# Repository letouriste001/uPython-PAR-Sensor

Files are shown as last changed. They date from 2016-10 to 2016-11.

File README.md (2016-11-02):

# uPython-PAR-Sensor

## Introduction
Cette librairie est écrite pour un capteur TSL 230 RD qui nous permet de mesurer le PAR
L’ensoleillement représente la mesure d’irradiance du PAR  (Photosynthetically active radiation). Le PAR est le rayonnement nécessaire à la photosynthèse qui se situe sur une plage de 400 à 700 nm de longueur d’onde , c’est à dire une grande partie du spectre du domaine visible (fig.1).

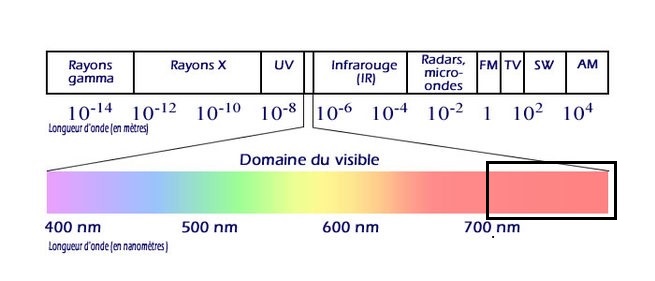
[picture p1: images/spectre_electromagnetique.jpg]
Spectre électromagnétique


Figure 1 Spectre électromagnétique, agrandissement sur le spectre visible. En noir, la partie du spectre visible non utilisée dans le PAR.

Pour mesurer la fiabilité du capteur TSL 230 RD on l’a comparé au capteur SUD033 couplet a un IL1700. Après une journée de mesure on obtient les courbes suivantes (fig.2)

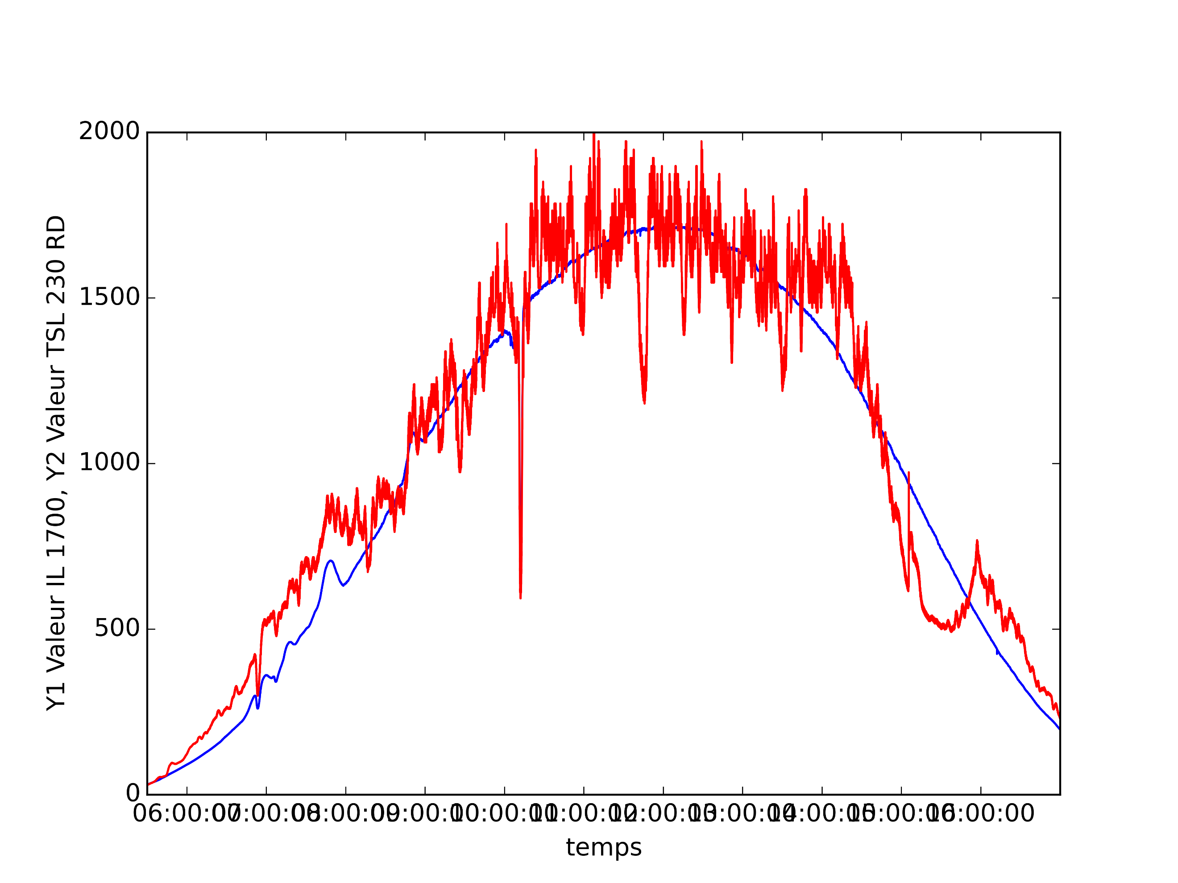
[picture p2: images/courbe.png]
Courbe des capteurs


Figure 2 Graphique de mesure des capteurs IL1700 et TSL 230 RD

La courbe rouge a été mise à l’échelle d’un facteur trois pour mieux visualiser le fait que les deux courbes sont similaires.
On applique la régression linaire sur les valeurs des capteurs (fig.3).

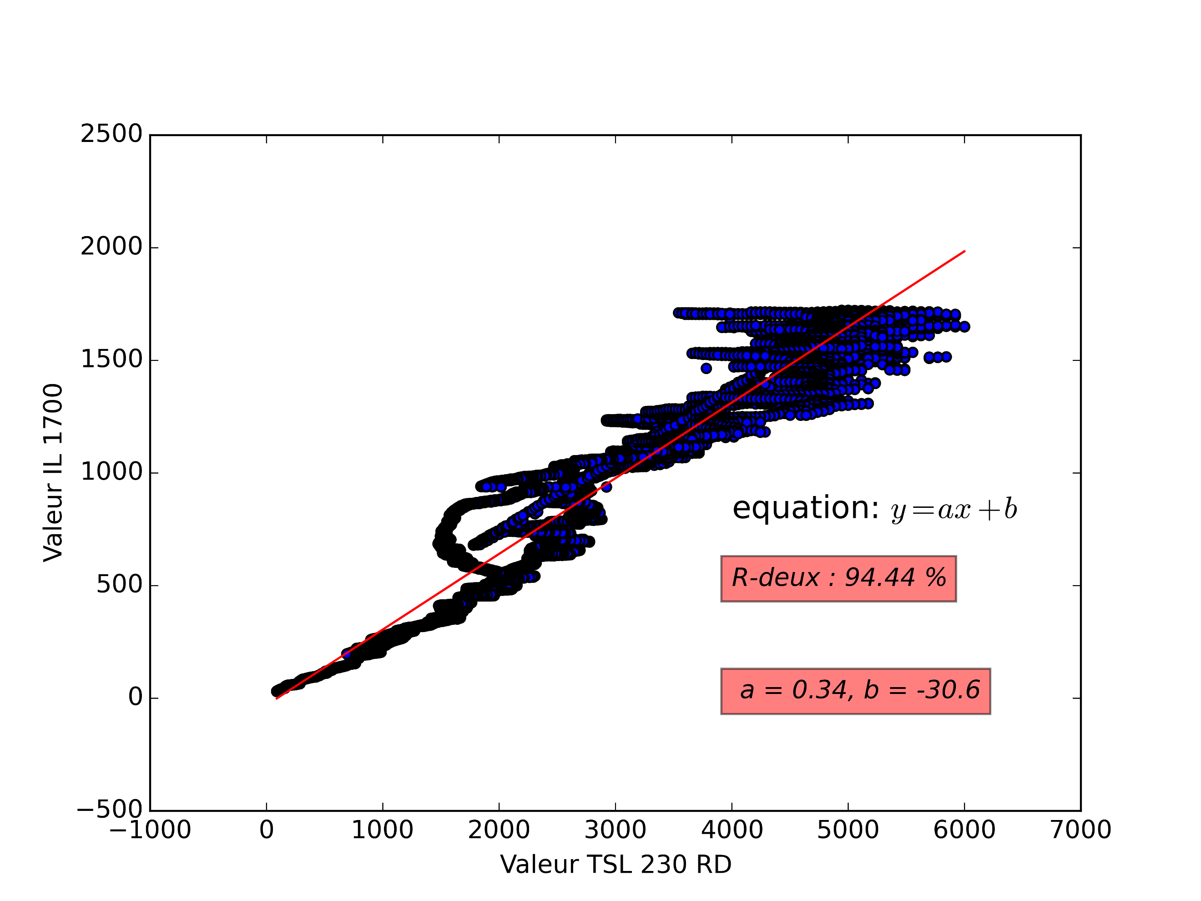
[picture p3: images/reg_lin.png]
Régression linéaire


Figure 3 Représentation de la régression linaire entre les capteurs IL1700 et TSL230 RD

On constate après calcul que le coefficient de corrélation et de 94.4% ce qui est plutôt bon.
On utilisera les coefficient a et b pour calculer les valeur en μE m−2 s−1

Les conditions de test étant mauvais (coffret plexiglas abimer, alimentation non filtrer, etc.) (fig.4).

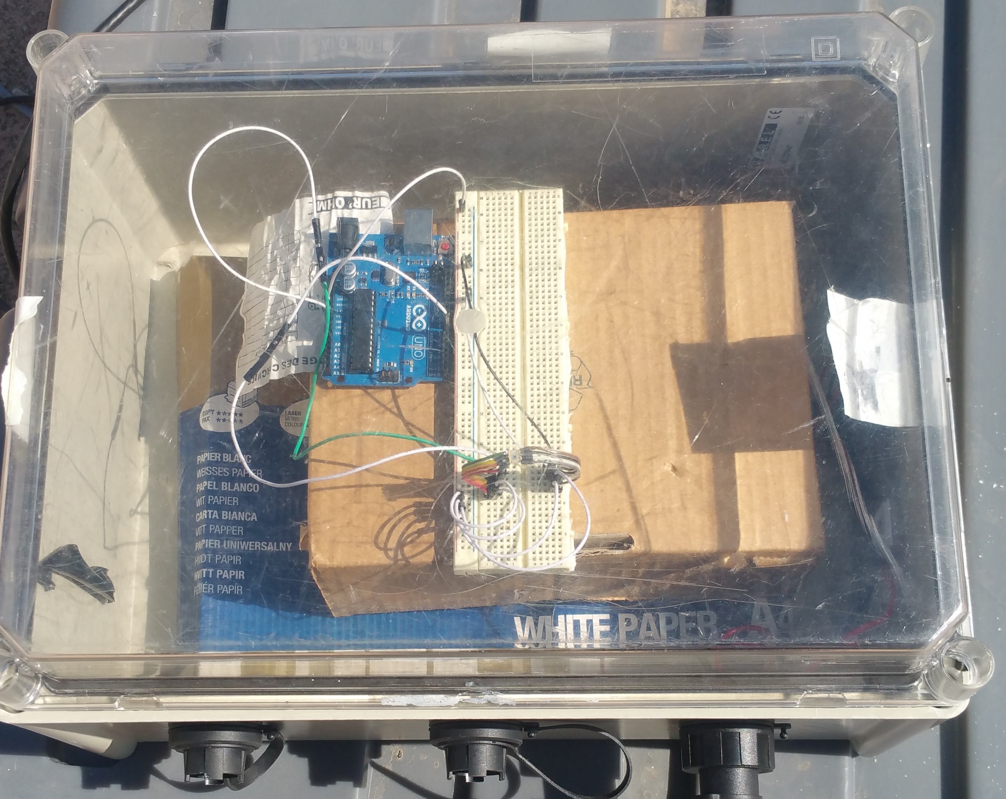
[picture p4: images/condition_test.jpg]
Condition de test


Figure 4 Coffret de test du capteur de PAR premier test effectuer sur Arduino.

## Design PCB

Après les tests du capteur et dans un but d’amélioration de la lecture des valeurs j’ai réalisé ceci (fig.5) (le PCB est disponibles sur le dépôt): 

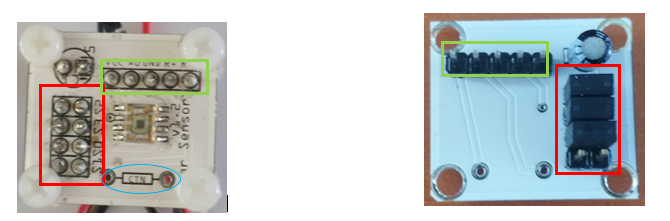
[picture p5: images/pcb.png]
PCB


Figure 5 Photographie des pcb recto verso. En rouge la configuration de la sensibilité. En vert les pins de connexion et en Bleu une CTN pour correction de la valeur mesurer en fonction de la température.

Composant pour le PCB:

* TSL 230 RD x1
* Condensateur 1 µF (6V min) x1
* pin header male 2 pin x4
* pin header male 5 pin x1
* strap informatique x4

## Adaptation pour Pyboard

Le capteur de par fonctionent en 5v et le pyboard en 3v3, on va adapter la tention de sortie a l'aide d'un pont diviseur de tention. (le PCB est disponibles sur le dépôt)

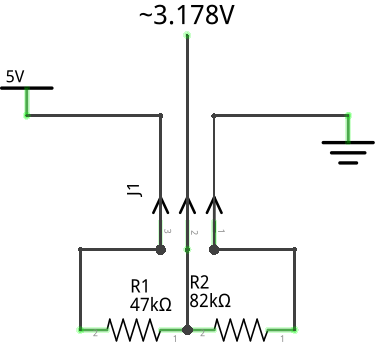
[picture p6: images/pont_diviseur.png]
Pont diviseur


Composant pour le PCB:

* Résistance R1 47 kΩ ±1%
* Résistance R2 82 kΩ ±1%
* pin header male 3 pin x1
* pin header male 1 pin x4 optional

## Code d'exemple

En cour de rédaction

## Réference

En cour de rédaction

## TODO List

- [x] ecrire le Readme
- [] ecrire le Readme anglais
- [x] ajouter la licence
- [x] ajouter le PCB
- [] ajouter la modele de cablage pyboard et carte par
- [x] lister les composant pour PCB
- [x] Ajouter les commentaires au code
- [] ajouter les commentaires au code en anglais
- [x] tester le code V beta
- [x] tester le code V 1.0
- [x] ajouter le code de demonstration
- [] ameliorer la qualité de la regression lineaire
- [] verifier la formule de conversion frequence µW / cm2
- [x] ajouter la partie adaptation Pyboard
- [x] ajouter les references
- [] corriger l'orthographe
- [] ajouter le systeme de correction de la valeur mesurer en fonction de la temperature
- [] modifier la taille des images

## English readme

Comming soon

## Copyright and Licence

[Licence MIT](/LICENSE.md)
Copyright (c) 2016 Christophe AUBERT

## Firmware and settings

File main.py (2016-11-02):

__author__ = "Christophe AUBERT"
__copyright__ = "Copyright 2016"
__credits__ = ["Christophe AUBERT"]
__license__ = "MIT"
__version__ = "1.0.1"
__maintainer__ = "Christophe AUBERT"
__status__ = "development"

import pyb
import TSL230RD


blueled=pyb.LED(4)
blueled.on()

# pas obligatoire on peux faire :
# TSL230RD.init
# et remplacer tout les par_sensor par TSL230RD

par_sensor = TSL230RD
par_sensor.init()

while 1:
    
    freq = par_sensor.raw_measure()
    print("Frequence : " + str(freq) + " Hz")
    einstein = par_sensor.Einstein_by_m2_by_second_measure(freq)
    print("PAR : " + str(einstein) + " uE/m2/s")
    uwatt = par_sensor.uwatt_by_cm2_measure(freq)
    print("PAR : " + str(uwatt) + " uW/m2/s")
    # attention il est important pour la mesure unique de mettre un delais de 1s entre chaque mesure
    pyb.delay(1000)
    
    # meme calcul mais avec la valeur moyenner sur 10 valeurs
    freq_a = par_sensor.raw_average(10)
    print("Frequence : " + str(freq_a) + " Hz")
    einstein = par_sensor.Einstein_by_m2_by_second_measure(freq_a)
    print("PAR : " + str(einstein) + " uE/m2/s")
    uwatt = par_sensor.uwatt_by_cm2_measure(freq_a)
    print("PAR : " + str(uwatt) + " uW/m2/s")
    

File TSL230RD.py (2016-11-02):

"""TSL230RD.py: Capteur de par pour pybboard."""

__author__ = "Christophe AUBERT"
__copyright__ = "Copyright 2016"
__credits__ = ["Christophe AUBERT"]
__license__ = "MIT"
__version__ = "1.0.1"
__maintainer__ = "Christophe AUBERT"
__status__ = "development"

import pyb

# Constantes
FACOTR_A = 0.34
FACOTR_B = -30.6

# Cf datasheet TSL230 RD
DARK_FREQUENCY = 0.4
RESPONSIVITY = 790

# Cf micro python reference
# variable compteur de microsecondes
TIMER = 2
PRESCALER = 83
PERIOD = 0x0fffffff

# variables globales
timer = 0
t2 = None
period = 1
f0_scalling = 0

def callback(line):
    """
    Fonction de callback appeler quand un evenement exterieur sur la pin parametrer en init.
    cette fonction permet de mesurer la durer d'une periode.
    :param line: voir documention upython.
    """
    global timer
    global t2
    global period
    
    tmp = t2.counter()
    period = tmp - timer
    timer = tmp

def raw_average(time_average=10):
    """
    La fonction raw_average permet de faire une moyenne des valeur brute lue sur une periode donnee
    :param time_average: Paremetre de temps qui definit la periode de temps sur laquelle on va effectuer la moyenne.
    :return: retourne la moyenne des valeur lue sur une periode de temps definit.
    """
    sum = 0.0
    # boucle pour sommer les valeurs brutes
    for i in range(0, (time_average - 1)):
        sum += raw_measure()
        pyb.delay(1000)  # delais 1s
    
    # verification pour la division par zero
    try:
        return sum / time_average
    except ZeroDivisionError:
        print("division by zero, time average is bad, please change value")
        return -1

def raw_measure():
    """
    La fonction raw_measure renvoie la valeur brute d'ensoleillement du capteur en Hz
    :return: valeur mesurer par le capteur de PAR en Hz
    """
    
    global period
    
    # Test de la division par zero
    try:
        return 1000000 / period
    except ZeroDivisionError:
        print("division by zero, period is null, please check your wiring")
        return -1

# TODO en cour, amelioration, Beta
def uwatt_by_cm2_measure(raw_measure):
    """
    Fonction qui convertie la valeur brute du capteur en uwatt/cm2
    :return: la valeur convertie
    """
    global f0_scalling
    return ((raw_measure * f0_scalling) - DARK_FREQUENCY) / RESPONSIVITY


# TODO en cour, amelioration des facteur A et B, Beta
def Einstein_by_m2_by_second_measure(raw_measure):
    """
    Fonction qui donne la valeur d'ensoleillement en uE/m2/s
    :param raw_measure: valeur brute du capteur
    :return: Renvoie la valeur convertir en uE/m2/s
    """
    return ((raw_measure * FACOTR_A) + FACOTR_B)


def init(pin_name='X1', scalling=100):
    """
    Fonction d'inistilisation du capteur de par
    :param pin_name: identifiant du GPIO ou est connecter le capteur. par defaut la valeur et X1
    """
    global t2
    global f0_scalling
    
    f0_scalling = scalling  # valeur de scalling configurer sur le capteur
    
    # definition de la pin utiliser pas le capteur de par pour l'aquisition de donnée
    pin = pyb.Pin(pin_name, pyb.Pin.IN)
    pyb.Pin(pin)
    # parametrage du timer à 1 MHz.
    t2 = pyb.Timer(TIMER, prescaler=PRESCALER, period=PERIOD)
    # declaration d'une action sur evenement exterieur.
    pyb.ExtInt(pin, pyb.ExtInt.IRQ_RISING, pyb.Pin.PULL_UP, callback)
    # ajout d'un delais de demarage au capteur pour avoir une valeur de mesure correcte
    pyb.delay(3000)  # delais 3s

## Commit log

2016-09-16 Capteur de par v0.1, fonction de callback pour les event ext, fonction de mesure qui donne la valeur en herz de l'irradiance, fonction d'init du capteur. A rajouter le commentaire, ameliorer la mesur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
2016-09-19 ajout de la fonction mesure en watt/m2
2016-10-18 modification de la fonction mesure de watt/m2 en uwatt/cm2 ajoute de la fonction de moyenne de la valeur brute ajout de la fonction uwatt/cm2 moyenner ajout de la fonction uE/m2/s ajout de la fonctio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
2016-10-18 Ajout des informations de licene, d'auteur etc.
2016-10-18 supression des variables magiques ajout des commentaires sur les fonctions
2016-10-18 Ajout du readme ajout des photo du readme
2016-10-18 Ajout du fichier de license
2016-10-18 ajout information readme
    [Capteur PAR.fzz]
2016-10-18 Ajout du capteur TSL230RD et re nomage du dossier PCB en Fritzing
    [Capteur PAR.fzz]
2016-10-18 ajout de la liste du materiel pour le PCB
2016-10-18 ajout de la partie adaptation pyboard
    [Pont Diviseur univesel.fzz]
2016-11-02 correction de bug ajout du code d'exemple dans main.py mise a jour de readme
    [TSL230RD.py, main.py]
